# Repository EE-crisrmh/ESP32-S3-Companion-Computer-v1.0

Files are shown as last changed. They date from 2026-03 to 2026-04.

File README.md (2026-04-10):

# ESP32-S3-DevBoard-v1.0

## Overview
This project is the first version of my **ESP32-S3**. The purpose of this board is to act as a **wireless communication, expansion, and development support board**.

This board is intended to handle **higher-level support functions** such as wireless communication, sensor interfacing, debugging, and future peripheral expansion.

This is **Version 1.0**, meaning the primary goal was to design and lay out a functional first revision that establishes the core architecture for future integration and testing.

---

## Project Goals
The main goals of this board were to:

- Build a **modular companion board** for a future platforms
- Create a hardware platform around the **ESP32-S3**
- Add support for **wireless communication and external peripherals**
- Provide **easy bring-up, programming, and debugging access**
- Establish a foundation for future onboard communication, telemetry, and sensor expansion

---

## Current Features

### Core Hardware
- **ESP32-S3 WiFi module**
- **4-layer PCB design**
- **USB-C power input**
- **LM1117DT-3.3V LDO regulator**
- **ESP-PROG compatible programming/debug header**

### User / Bring-Up Features
- **BOOT switch**
- **RESET switch**
- **USER switch**
- **RGB LEDs**
- **Green power LED**

### Sensor / Expansion Features
- **SI7021-GMR temperature and humidity sensor** on the **I2C bus**
- **QWIIC connector** for external I2C peripherals
- **2x5 SPI expansion header**
  - planned for future peripherals such as a **W5500 Ethernet module**

### Mechanical
- **3.2 mm mounting holes**

---

## PCB Stack-Up
This board was designed as a **4-layer PCB** to improve routing flexibility, grounding, and power distribution.

### Stack-Up
- **Top Layer**
- **0.196 mm prepreg**
- **Inner Layer 1**
- **1.03 mm core**
- **Inner Layer 2**
- **0.196 mm prepreg**
- **Bottom Layer**

This stack-up was chosen to provide a better structure for embedded routing compared to a simpler 2-layer design.

---

## Why I Built This
I wanted to start building the electronics architecture for my own **autonomous drone system** rather than only working with off-the-shelf development boards.

This board is one of the first major hardware building blocks in that process.

The idea is to split the system into multiple roles:

- **STM32 board** → real-time flight control / lower-level control tasks
- **ESP32-S3 companion board** → communication, expansion, debugging, and support functions

This gives me a cleaner system architecture and more flexibility as the project grows.

## Design Focus for v1.0
For Version 1.0, the focus was on:

- Building a clean first-pass board architecture
- Integrating the core ESP32-S3 support hardware
- Adding modular expansion interfaces
- Making firmware flashing and bring-up easier
- Creating a platform that can be improved in future revisions

This version is primarily about getting the **hardware foundation** in place.

---

## Future Plans
This board is still in its early stages, and future revisions will likely include both electrical and firmware improvements.

### Planned Next Steps
- Order and assemble the first revision of the board
- Perform initial bring-up and power validation
- Verify USB-C power and 3.3V regulation
- Test programming/debug functionality with ESP-PROG
- Bring up onboard LEDs, switches, and sensor interfaces
- Validate I2C and SPI expansion functionality

### Long-Term Plans
- Pair this board with a **custom STM32 flight controller**
- Use it as part of a full **autonomous drone electronics stack**
- Add communication between the ESP32-S3 and STM32
- Expand support for telemetry and external peripherals
- Potentially integrate Ethernet or other network-capable modules for development and testing
- Continue revising the board based on testing and system needs

---

## Version
**Current Version:** `v1.0`

This is the first revision of the board and is intended to serve as the initial hardware foundation for future testing and iteration.

---

## Author
Designed and developed by me as part of my long-term embedded systems / autonomous drone project.

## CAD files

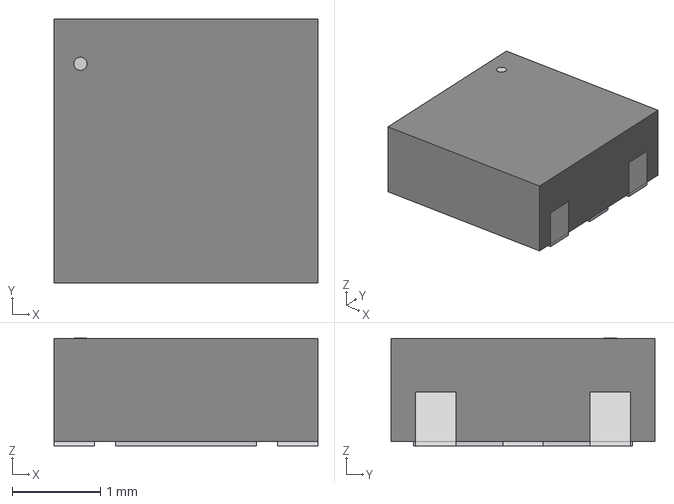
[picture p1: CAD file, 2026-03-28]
Docs/DFN6_3X3_SIL.step
3.00 x 3.00 x 1.22 mm

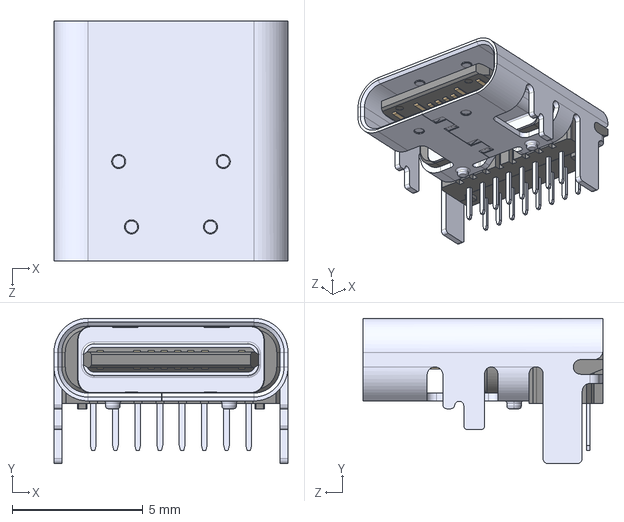
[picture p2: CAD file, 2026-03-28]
Docs/USB4085-GF-A_REVA4.step
8.95 x 5.56 x 9.17 mm

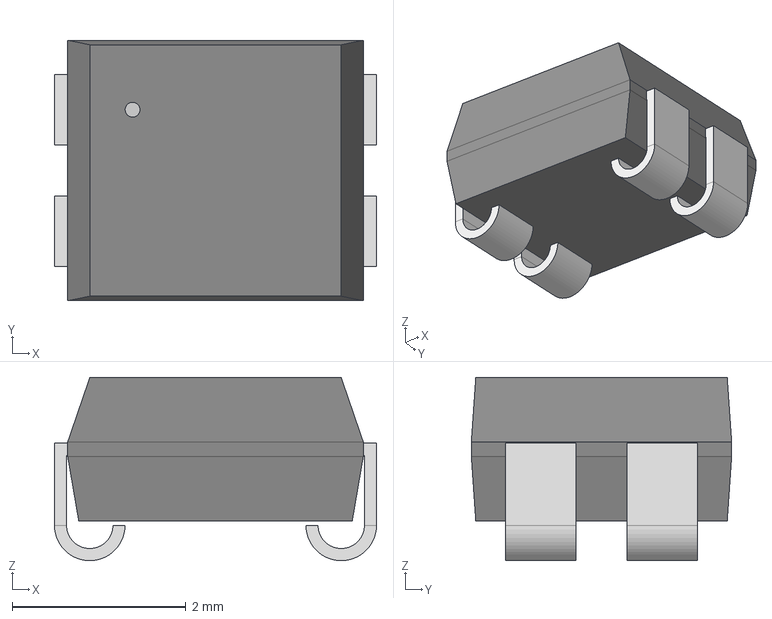
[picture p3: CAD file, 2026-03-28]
Docs/PLCC4_CLV1L-FKB_CRW.step
3.71 x 3.00 x 2.11 mm

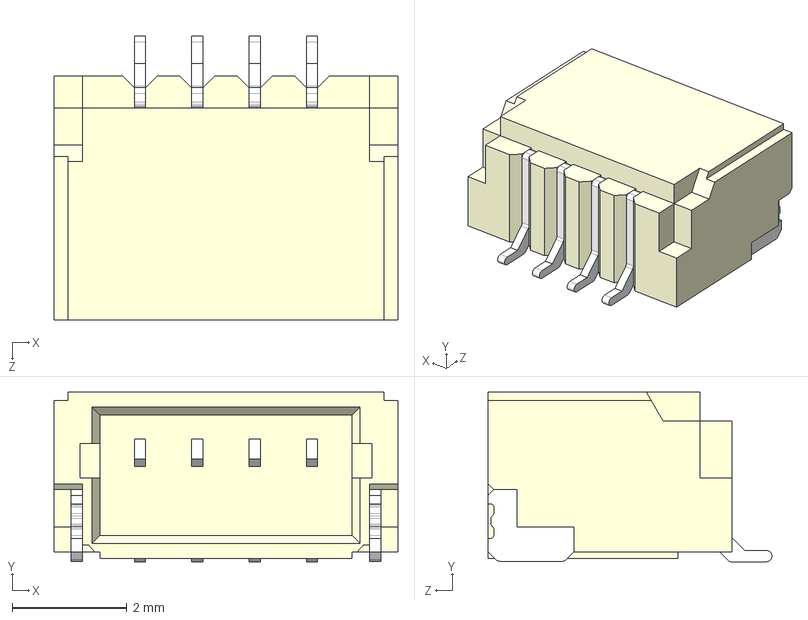
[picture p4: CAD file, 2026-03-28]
Docs/SM04B-SRSS-TB_LF__SN_.step
6.00 x 2.96 x 4.95 mm

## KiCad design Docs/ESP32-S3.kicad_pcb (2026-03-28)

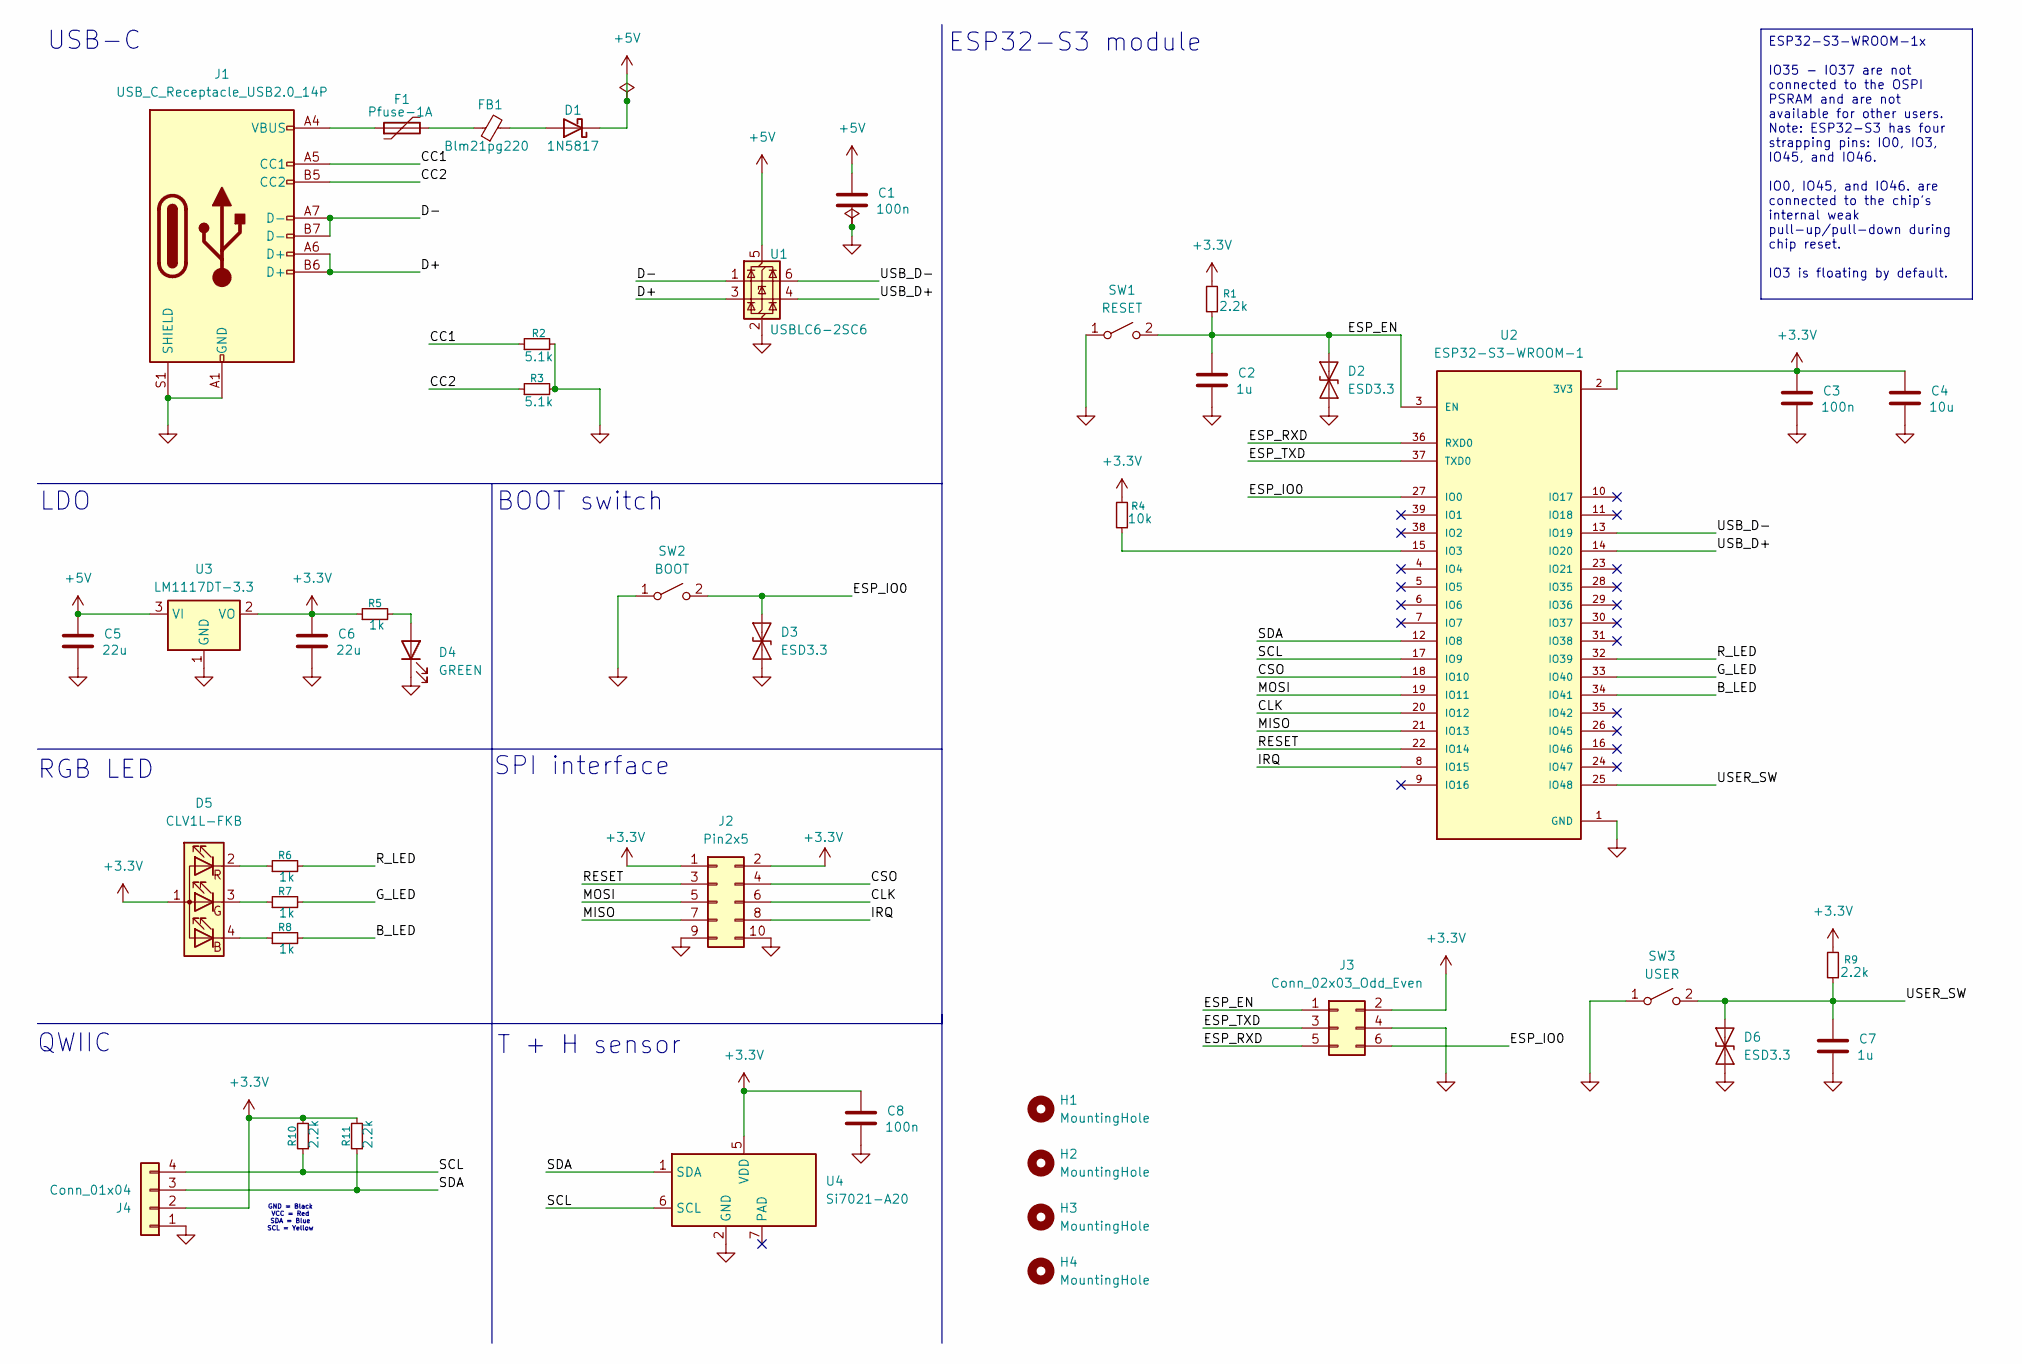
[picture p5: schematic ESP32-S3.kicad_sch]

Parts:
C1, C3, C8: 100n; C_0402_1005Metric
C2, C7: 1u; C_0603_1608Metric
C4: 10u; C_0603_1608Metric
C5, C6: 22u; C_0805_2012Metric
D1: 1N5817; D_DO-41_SOD81_P7.62mm_Horizontal
D2, D3, D6: ESD3.3; D_SOD-923
D4: GREEN; LED_0805_2012Metric
D5: CLV1L-FKB; LED_Cree-PLCC4_3.2x2.8mm_CCW
F1: Pfuse-1A; D_1206_3216Metric
FB1: Blm21pg220; L_0805_2012Metric
H1, H2, H3, H4: MountingHole; MountingHole_3.2mm_M3
J1: USB_C_Receptacle_USB2.0_14P; USB_C_Receptacle_HRO_TYPE-C-31-M-12
J2: Pin2x5; PinHeader_2x05_P2.54mm_Vertical
J3: Conn_02x03_Odd_Even; PinHeader_2x03_P2.54mm_Vertical
J4: Conn_01x04; JST_SH_SM04B-SRSS-TB_1x04-1MP_P1.00mm_Horizontal
R1, R9, R10, R11: 2.2k; R_0402_1005Metric
R2, R3: 5.1k; R_0402_1005Metric
R4: 10k; R_0402_1005Metric
R5, R6, R7, R8: 1k; R_0805_2012Metric
SW1: RESET; SW_SPST_B3U-1000P
SW2: BOOT; SW_SPST_B3U-1000P
SW3: USER; SW_Tactile_SPST_Angled_PTS645Vx39-2LFS
U1: USBLC6-2SC6; SOT-23-6
U2: ESP32-S3-WROOM-1; PARTREV v1.0
U3: LM1117DT-3.3; TO-252-3_TabPin2
U4: Si7021-A20; DFN-6-1EP_3x3mm_P1mm_EP1.5x2.4mm

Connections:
+3.3V: C3.1, C4.1, C6.1, C8.1, D5.1 (A), J2.1, J2.2, J3.2, J4.2, R1.2, R4.2, R5.1, R9.2, R10.2, R11.2, U2.2 (3V3), U3.2 (VO), U4.5 (VDD)
+5V: C1.1, C5.1, D1.1 (K), U1.5 (VBUS), U3.3 (VI)
/B_LED: R8.2, U2.34 (IO41)
/CC1: J1.A5 (CC1), R2.1; also elsewhere on the board
/CC2: J1.B5 (CC2), R3.1; also elsewhere on the board
/CLK: J2.6, U2.20 (IO12)
/CSO: J2.4, U2.18 (IO10)
/D+: J1.A6 (D+), J1.B6 (D+), U1.3 (I/O2); also elsewhere on the board
/D-: J1.A7 (D-), J1.B7 (D-), U1.1 (I/O1); also elsewhere on the board
/ESP_EN: C2.1, D2.2 (A2), J3.1, R1.1, SW1.2 (B), U2.3 (EN)
/ESP_IO0: D3.2 (A2), J3.6, SW2.2 (B), U2.27 (IO0)
/ESP_RXD: J3.5, U2.36 (RXD0)
/ESP_TXD: J3.3, U2.37 (TXD0)
/G_LED: R7.2, U2.33 (IO40)
/IRQ: J2.8, U2.8 (IO15)
/MISO: J2.7, U2.21 (IO13)
/MOSI: J2.5, U2.19 (IO11)
/RESET: J2.3, U2.22 (IO14)
/R_LED: R6.2, U2.32 (IO39)
/SCL: J4.4, R10.1, U2.17 (IO9), U4.6 (SCL)
/SDA: J4.3, R11.1, U2.12 (IO8), U4.1 (SDA)
/USB_D+: U1.4 (I/O2), U2.14 (IO20)
/USB_D-: U1.6 (I/O1), U2.13 (IO19)
/USER_SW: C7.1, D6.2 (A2), R9.1, SW3.2 (B), U2.25 (IO48); also elsewhere on the board
GND: C1.2, C2.2, C3.2, C4.2, C5.2, C6.2, C7.2, C8.2, D2.1 (A1), D3.1 (A1), D4.1 (K), D6.1 (A1), J1.A1 (GND), J1.A12 (GND), J1.B1 (GND), J1.B12 (GND), J1.S1 (SHIELD), J2.9, J2.10, J3.4, J4.1, R2.2, R3.2, SW1.1 (A), SW2.1 (A), SW3.1 (A), U1.2 (GND), U2.1 (GND), U2.40 (GND), U2.41_1 (GND), U2.41_2 (GND), U2.41_3 (GND), U2.41_4 (GND), U2.41_5 (GND), U2.41_6 (GND), U2.41_7 (GND), U2.41_8 (GND), U2.41_9 (GND), U3.1 (GND), U4.2 (GND); also elsewhere on the board
unnamed: D1.2 (A), FB1.2
unnamed: D4.2 (A), R5.2
unnamed: D5.4 (BK), R8.1
unnamed: D5.3 (GK), R7.1
unnamed: D5.2 (RK), R6.1
unnamed 30: F1.1, J1.A4 (VBUS), J1.A9 (VBUS), J1.B4 (VBUS), J1.B9 (VBUS); also elsewhere on the board
unnamed: F1.2, FB1.1
unnamed: R4.1, U2.15 (IO3)

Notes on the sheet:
GND = Black VCC = Red SDA = Blue SCL = Yellow
ESP32-S3 module
USB-C
RGB LED
BOOT switch
QWIIC
T + H sensor
LDO
SPI interface
ESP32-S3-WROOM-1x IO35 - IO37 are not connected to the OSPI PSRAM and are not available for other users. Note: ESP32-S3 has four strapping pins: IO0, IO3, IO45, and IO46. IO0, IO45, and IO46. are connected to the chip's internal weak pull-up/pull-down during chip reset. IO3 is floating by default.

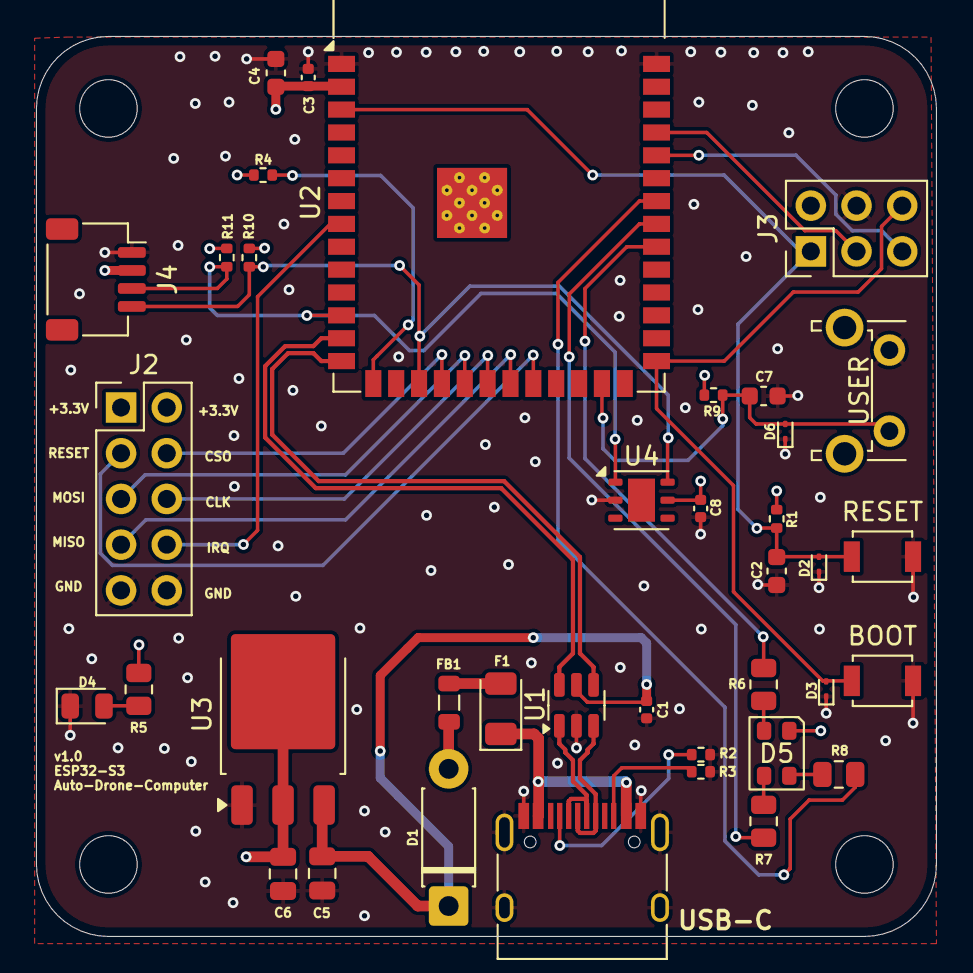
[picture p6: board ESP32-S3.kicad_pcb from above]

Board: 4 copper layers, 50.0 x 50.0 mm, 42 parts (0 on the bottom side), 33 nets.

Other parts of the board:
USB-C: USB_C_Receptacle_USB2.0_14P; USB_C_Receptacle_HRO_TYPE-C-31-M-12
USER: USER; SW_Tactile_SPST_Angled_PTS645Vx39-2LFS

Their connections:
/CC1: USB-C.A5 (CC1); also elsewhere on the board
/CC2: USB-C.B5 (CC2); also elsewhere on the board
/D+: USB-C.A6 (D+), USB-C.B6 (D+); also elsewhere on the board
/D-: USB-C.A7 (D-), USB-C.B7 (D-); also elsewhere on the board
/USER_SW: USER.2 (B); also elsewhere on the board
GND: USB-C.A1 (GND), USB-C.A12 (GND), USB-C.B1 (GND), USB-C.B12 (GND), USB-C.S1 (SHIELD), USER.1 (A); also elsewhere on the board
unnamed 30: USB-C.A4 (VBUS), USB-C.A9 (VBUS), USB-C.B4 (VBUS), USB-C.B9 (VBUS); also elsewhere on the board
